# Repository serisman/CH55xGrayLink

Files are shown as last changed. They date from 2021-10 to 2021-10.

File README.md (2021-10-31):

# CH55xGrayLink
A sketch for CH551/CH552 based Arduinos (using [Ch55xduino](https://github.com/DeqingSun/ch55xduino)) that makes it possible to connect a Texas Instruments calculator to a computer using USB.

## Introduction
This sketch allows a computer to connect to and transfer data to/from a TI graphing calculator over USB.
It is a port of the *serial2ti83* Arduino sketch for Arduino Nano/Uno found [here](https://github.com/MTres19/serial2ti83).
In order to use it, compile and upload `CH55xGrayLink.ino` to a CH551 or CH552 [Ch55xduino](https://github.com/DeqingSun/ch55xduino) board using the Arduino IDE.

```
Sketch uses 4254 bytes (41%) of program storage space. Maximum is 10240 bytes.
Global variables use 59 bytes (16%) of dynamic memory, leaving 305 bytes for local variables. Maximum is 364 bytes.
```

## Wiring
Connect the following pins to the 2.5mm port located at the bottom of the TI calculator according to the following table:

| 2.5mm port | CH55x | 
|:---:|:---:|
| tip | P1.4 |
| ring | P1.7 |
| sleeve | GND |

## Transfer Speed
Max reported transfer speed seems to be about 3.2 KB/s based on testing done to date (TI-83 Plus).

## Arduino Settings
First, install Ch55xduino according to the instruction found here: https://github.com/DeqingSun/ch55xduino#installation

Then, select the CH551 Board (or CH552 Board) and adjust the other settings to match below.

Adjust *Port* as needed.  May need to use Device Manager to force the port to COM1-4 for TI programs to actually see it.

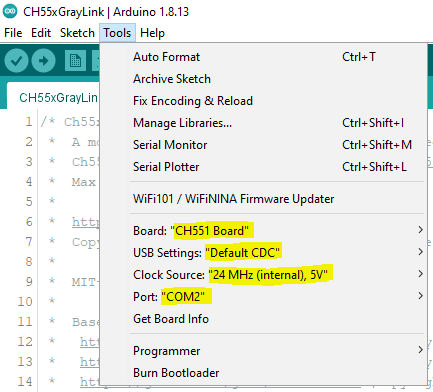
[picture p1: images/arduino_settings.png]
arduino_settings


## Schematic

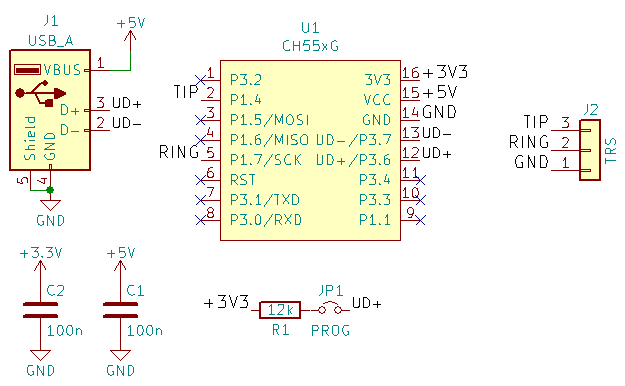
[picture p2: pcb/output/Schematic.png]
Schematic


## PCB
Designed to fit within a standard USB-A male port housing.

Gerbers: `pcb/output/gerber.zip`

PCBs available from: [OSHPARK](https://oshpark.com/shared_projects/HASfmay6)

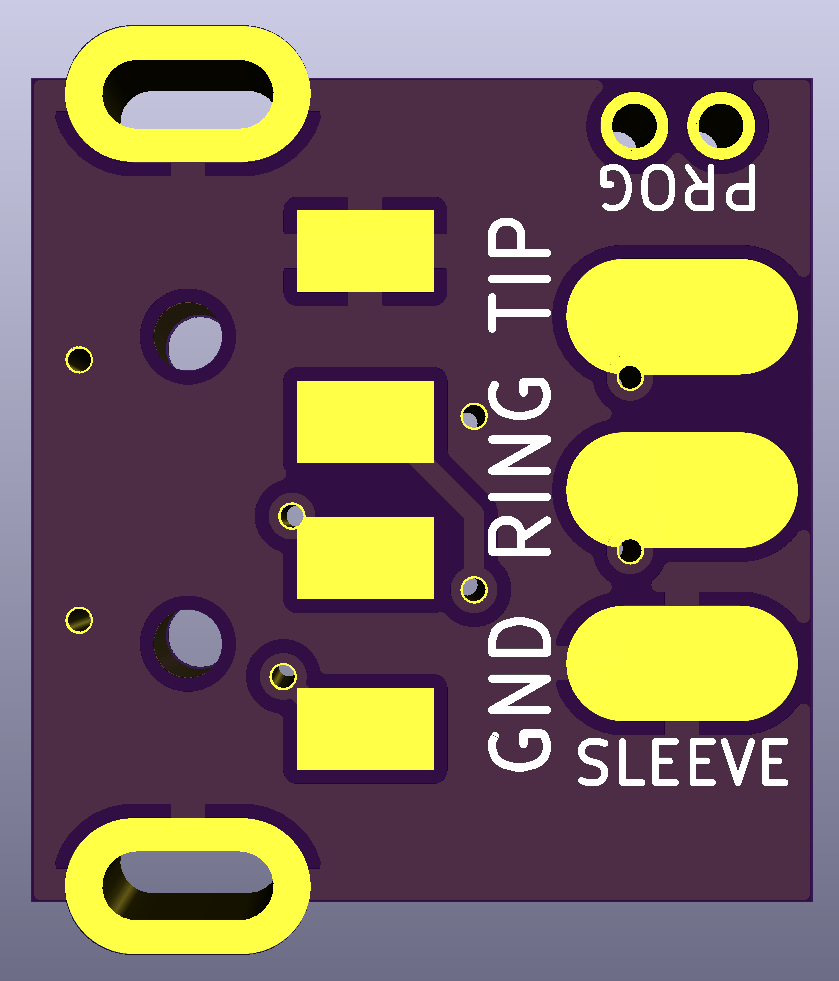
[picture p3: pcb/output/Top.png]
Top

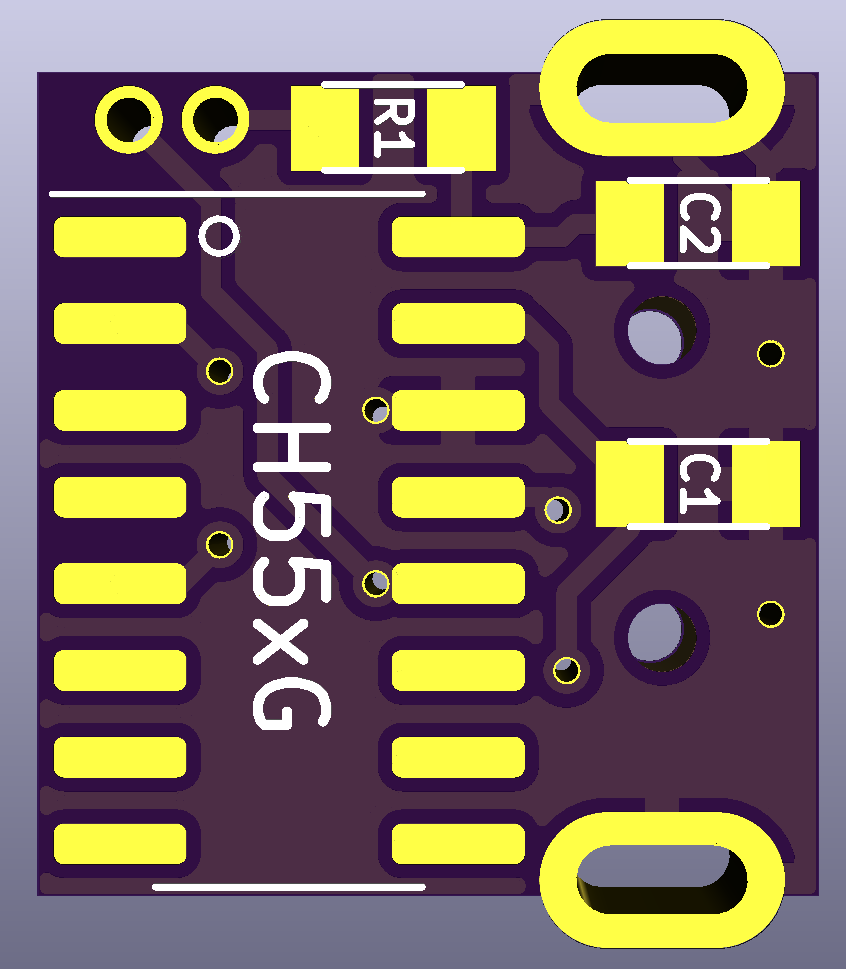
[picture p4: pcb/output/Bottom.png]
Bottom


## Finished Cable
Note: This is picturing an older PCB (from a different project), but the optimized PCB available above is basically the same thing.

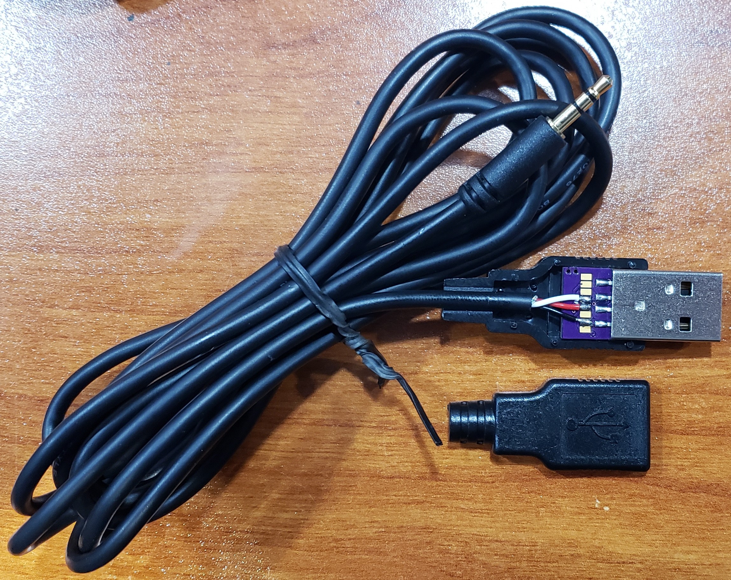
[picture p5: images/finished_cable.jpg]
Finished Cable

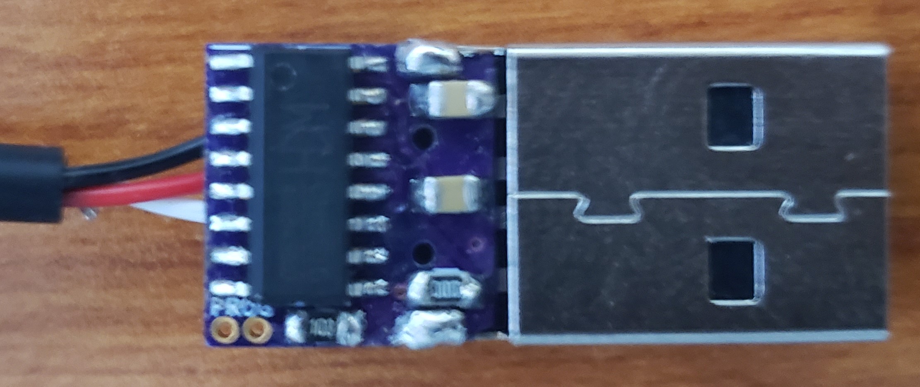
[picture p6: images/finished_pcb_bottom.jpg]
Finished PCB Bottom


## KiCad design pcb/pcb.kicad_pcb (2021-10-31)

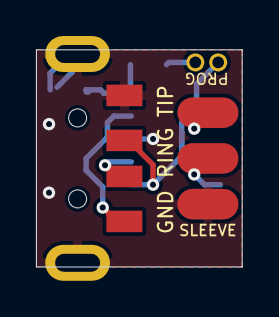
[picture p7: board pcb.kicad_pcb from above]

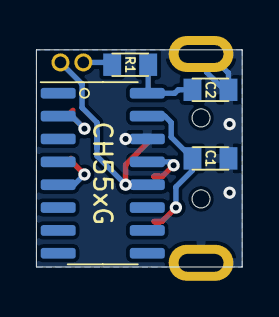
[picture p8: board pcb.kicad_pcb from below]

Board: 2 copper layers, 11.4 x 12.1 mm, 7 parts (5 on the bottom side), 8 nets.

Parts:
C1, C2: 100n; C_0805
J1: USB_A; USB_A_Horizontal_C319178
J2: TRS; PinHeader_1x03_P2.54mm_Horizontal
JP1: PROG; Jumper_P1.27mm
R1: 12k; R_0805
U1: CH55xG; SOIC-16_3.9x9.9mm_P1.27mm

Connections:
+3V3: C2.1, R1.2, U1.16
+5V: C1.1, J1.1, U1.15
/RING: J2.2, U1.5
/TIP: J2.3, U1.2
/UD+: J1.3, JP1.2, U1.12
/UD-: J1.2, U1.13
GND: C1.2, C2.2, J1.4, J1.5, J2.1, U1.14
unnamed: JP1.1, R1.1

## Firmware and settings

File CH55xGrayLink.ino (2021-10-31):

/* Ch55xGrayLink:
 *  A modern yet simple TI Graph-Link cable ported to Ch55xduino for CH551/CH552 MCUs
 *  Ch55xduino: (https://github.com/DeqingSun/ch55xduino)
 *  Max transfer speed: about 3.2 KB/s (TI-83 Plus)
 *
 *  https://github.com/serisman/Ch55xGrayLink
 *  Copyright (C) 2021 serisman <github@serisman.com>
 *
 *  MIT-licensed.
 *
 *  Based on:
 *   https://github.com/MTres19/serial2ti83 (Copyright (C) 2018 Matthew Trescott)
 *   https://github.com/DSchndr/serial2ti83 (Copyright (C) 2018 DSchndr)
 *   https://github.com/jw0k/serial2ti83 (Copyright (C) 2017 jw0k)
 */

#define TXTIMEOUT   65000UL
#define RXTIMEOUT   65000UL

#define PIN_TIP       P1_4
#define PIN_RING      P1_7
#define BM_TIP        (uint8_t)0b00010000
#define BM_RING       (uint8_t)0b10000000

inline bool TI_isTipHigh() { return PIN_TIP == 1; }
inline bool TI_isRingHigh() { return PIN_RING == 1; }

inline bool TI_isTipLow() { return PIN_TIP == 0; }
inline bool TI_isRingLow() { return PIN_RING == 0; }

inline void TI_pullTipLow() { PIN_TIP = 0; }
inline void TI_pullRingLow() { PIN_RING = 0; }

inline void TI_releaseTip() { PIN_TIP = 1; }
inline void TI_releaseRing() { PIN_RING = 1; }

void TI_setup() {
  // Configure both lines to be in Bidirectional mode (open-drain output with pull-up resistors and simultaneous input support)
  P1_MOD_OC = (BM_TIP | BM_RING);
  P1_DIR_PU = (BM_TIP | BM_RING);
  TI_releaseTip();
  TI_releaseRing();
}

void TI_sendByte(uint8_t byte) {
  unsigned int timeout;

  for (char i = 0; i < 8; ++i) {
    bool bit = byte & 0x01;
    byte >>= 1;

    // Poll both lines until they are both high, which means we're ready to send a bit
    timeout = TXTIMEOUT;
    while (TI_isTipLow() || TI_isRingLow()) {
      if (--timeout == 0) {
        return;
      }
    }

    if (bit) {
      // Send a bit by pulling appropriate line low
      TI_pullRingLow();

      // Wait for opposite line to become low
      timeout = TXTIMEOUT;
      while (TI_isTipHigh()) {
        if (--timeout == 0) {
          TI_releaseRing();
          return;
        }
      }

      // Release our line
      TI_releaseRing();

      // wait for opposite line to become high
      timeout = TXTIMEOUT;
      while (TI_isTipLow()) {
        if (--timeout == 0) {
          return;
        }
      }
    } else {
      // Send a bit by pulling appropriate line low
      TI_pullTipLow();

      // Wait for opposite line to become low
      timeout = TXTIMEOUT;
      while (TI_isRingHigh()) {
        if (--timeout == 0) {
          TI_releaseTip();
          return;
        }
      }

      // Release our line
      TI_releaseTip();

      // Wait for opposite line to become high
      timeout = TXTIMEOUT;
      while (TI_isRingLow()) {
        if (--timeout == 0) {
          return;
        }
      }
    }
  }
}

bool TI_getByte(uint8_t * byte) {
  // Return immediately if TI isn't trying to send us a byte (i.e. bus is idle)
  if (TI_isRingHigh() && TI_isTipHigh()) {
    return false;
  }

  uint8_t result = 0;
  unsigned int timeout;

  for (char i = 0; i < 8; ++i) {
    // Poll both lines until one of them becomes low
    timeout = RXTIMEOUT;
    while (TI_isRingHigh() && TI_isTipHigh()) {
      if (--timeout == 0) {
        return false;
      }
    }

    bool bit = TI_isRingLow();
    result >>= 1;

    if (bit) {
      result |= 0x80; // Bits are always transmitted LSb first (least significant bit)

      // Acknowledge a bit by pulling appropriate line low
      TI_pullTipLow();

      // Wait for opposite line to become high
      timeout = RXTIMEOUT;
      while (TI_isRingLow()) {
        if (--timeout == 0) {
          TI_releaseTip();
          return false;
        }
      }

      // release our line
      TI_releaseTip();
    } else {
      // Acknowledge a bit by pulling appropriate line low
      TI_pullRingLow();

      // Wait for opposite line to become high
      timeout = RXTIMEOUT;
      while (TI_isTipLow()) {
        if (--timeout == 0) {
          TI_releaseRing();
          return false;
        }
      }

      // Release our line
      TI_releaseRing();
    }

    // Wait for both lines stable high
    timeout = RXTIMEOUT;
    while (TI_isTipLow() || TI_isRingLow()) {
      if (--timeout == 0) {
        return false;
      }
    }
  }

  *byte = result;
  return true;
}

void setup() {
  // No need to init USBSerial
  TI_setup();
}

void loop() {
  // Forward incoming data from PC to the calculator
  while (USBSerial_available() > 0) {
      TI_sendByte(USBSerial_read());
  }

  // Forward incoming data from calculator to the PC
  uint8_t byteFromCalc;
  if (TI_getByte(&byteFromCalc)) {
    USBSerial_write(byteFromCalc);
  }
}

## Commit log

2021-10-30 Ported to Ch55xduino
    [circuit.fzz]
2021-10-31 Add Schematic, PCB, and pictures of finished cable
    [pcb.kicad_pcb, pcb.sch]
